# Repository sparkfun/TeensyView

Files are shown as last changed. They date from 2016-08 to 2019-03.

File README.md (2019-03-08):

SparkFun TeensyView
========================================

SparkFun TeensyView

[*SparkFun TeensyView (LCD-14048)*](https://www.sparkfun.com/products/14048)

An OLED display for the Teensy 3

Repository Contents
-------------------

* **/Hardware** - Eagle design files (.brd, .sch)
* **/Libraries** - Libraries for use with the TeensyView
* **/Production** - Production panel files (.brd)

Documentation
--------------
* **[Library](https://github.com/sparkfun/SparkFun_TeensyView_Arduino_Library/)** - C++ library for the TeensyView.
* **[Hookup Guide](https://learn.sparkfun.com/tutorials/teensyview-hookup-guide)** - Basic hookup guide for the TeensyView.
* **[SparkFun Fritzing repo](https://github.com/sparkfun/Fritzing_Parts)** - Fritzing diagrams for SparkFun products.
* **[SparkFun 3D Model repo](https://github.com/sparkfun/3D_Models)** - 3D models of SparkFun products. 
* **[SparkFun Graphical Datasheets](https://github.com/sparkfun/Graphical_Datasheets)** -Graphical Datasheets for various SparkFun products.

Product Versions
---------------------------------

* [LCD-14048](https://www.sparkfun.com/products/14048) - TeensyView product.

Compatible products
---------------------------------

* [DEV-13305](https://www.sparkfun.com/products/13305) - Teensy LC
* [DEV-13736](https://www.sparkfun.com/products/13736) - Teensy 3.2
* [DEV-14055](https://www.sparkfun.com/products/14055) - Teensy 3.5
* [DEV-14057](https://www.sparkfun.com/products/14057) - Teensy 3.6
* [DEV-12767](https://www.sparkfun.com/products/12767) - Teensy Audio Board
* [BOB-13311](https://www.sparkfun.com/products/13311) - Teensy 3.1 XBee Adapter
* [PRT-13925](https://www.sparkfun.com/products/13925) - Teensy Header Kit
* [DEV-13996](https://www.sparkfun.com/products/13996) - Teensy Prop Shield LC
* [DEV-13995](https://www.sparkfun.com/products/13995) - Teensy Prop Shield

Version History
---------------
* [V_1.0.0](https://github.com/sparkfun/TeensyView/tree/V_1.0.0) - Initial release

License Information
-------------------

This product is _**open source**_! 

Please review the LICENSE.md file for license information. 

If you have any questions or concerns on licensing, please contact techsupport@sparkfun.com.

Distributed as-is; no warranty is given.

- Your friends at SparkFun.

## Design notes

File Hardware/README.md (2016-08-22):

SparkFun <PRODUCT NAME> Design Files
=====================================

The .sch and .brd files hare are Eagle CAD schematic and PCB design files from SparkFun Electronics.
A freeware version of Eagle can be found [here](http://www.cadsoftusa.com/download-eagle/freeware/).

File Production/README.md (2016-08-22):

SparkFun <PRODUCT NAME> Production Files
=========================================

These are the production files SparkFun uses for printing PCBs.

License Information
-------------------
This product is open source! 

The hardware is released under [Creative Commons ShareAlike 4.0 International](https://creativecommons.org/licenses/by-sa/4.0/).

Please use, reuse, and modify these files as you see fit. Please maintain attribution to SparkFun Electronics and release anything derivative under the same license.

Distributed as-is; no warranty is given.

- Your friends at SparkFun.

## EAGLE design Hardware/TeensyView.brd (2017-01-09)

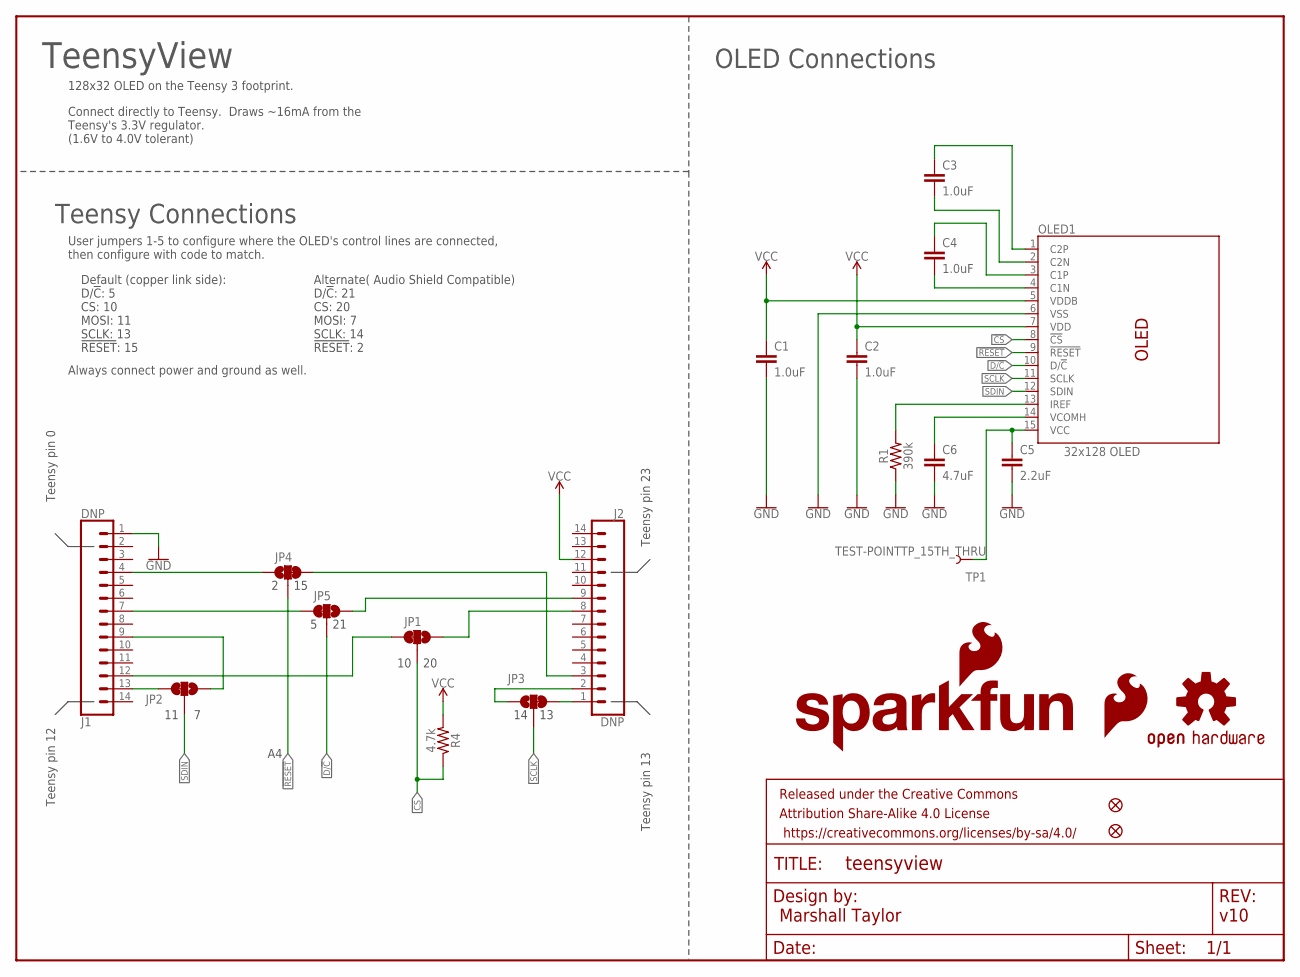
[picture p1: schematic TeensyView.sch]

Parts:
C1, C2, C3, C4: 1.0uF; 0402
C5: 2.2uF; 0805
C6: 4.7uF; 1206
FD1, FD2: FIDUCIALUFIDUCIAL; FIDUCIAL-MICRO
FRAME1: FRAME-LETTER; CREATIVE_COMMONS
J1, J2: DNP; 1X14_NO_SILK
JP1, JP2, JP3, JP4, JP5: JUMPER-SMT_3_1-NC_TRACE_SILK; SMT-JUMPER_3_1-NC_TRACE_SILK
LOGO1: SFE_LOGO_FLAME.1_INCH; SFE_LOGO_FLAME_.1
LOGO2: OSHW-LOGOS; OSHW-LOGO-S
LOGO3: SFE_LOGO_NAME_FLAME.1_INCH; SFE_LOGO_NAME_FLAME_.1
OLED1: 32x128 OLED; OLED-UG-2832TSWGG01-REAR
R1: 390k; 0603
R4: 4.7k; 0603
TP1: TEST-POINTTP_15TH_THRU; TP_15TH

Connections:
!CS: JP1.2, OLED1.8 (!CS!), R4.1
!RESET: JP4.2, OLED1.9 (!RESET!)
D/!C: JP5.2, OLED1.10 (D/!C!)
GND: C1.2, C2.2, C5.2, C6.2, J1.1, OLED1.6 (VSS), R1.1
unnamed: J1.12, JP1.3
unnamed: J2.8, JP1.1
unnamed: C4.2, OLED1.4 (C1N)
unnamed: C4.1, OLED1.3 (C1P)
unnamed: C3.2, OLED1.2 (C2N)
unnamed: C3.1, OLED1.1 (C2P)
unnamed: OLED1.13 (IREF), R1.2
unnamed: C6.1, OLED1.14 (VCOMH)
unnamed: C5.1, OLED1.15 (VCC), TP1.P$1
unnamed: J2.1, JP3.3
unnamed: J2.2, JP3.1
unnamed: J1.13, JP2.3
unnamed: J1.9, JP2.1
unnamed: J2.3, JP4.3
unnamed: J1.4, JP4.1
unnamed: J1.7, JP5.3
unnamed: J2.9, JP5.1
SCLK: JP3.2, OLED1.11 (SCLK)
SDIN: JP2.2, OLED1.12 (SDIN)
VCC: C1.1, C2.1, J2.12, OLED1.5 (VDDB), OLED1.7 (VDD), R4.2

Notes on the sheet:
v10
Marshall Taylor
Teensy pin 0
Teensy pin 12
Teensy pin 13
Teensy pin 23
128x32 OLED on the Teensy 3 footprint.
User jumpers 1-5 to configure where the OLED's control lines are connected, then configure with code to match.
TeensyView
Connect directly to Teensy. Draws ~16mA from the Teensy's 3.3V regulator. (1.6V to 4.0V tolerant)
Teensy Connections
OLED Connections
Default (copper link side): D/!C!: 5 CS: 10 MOSI: 11 SCLK: 13 !RESET!: 15
Alternate( Audio Shield Compatible) D/!C!: 21 CS: 20 MOSI: 7 SCLK: 14 !RESET!: 2
Always connect power and ground as well.

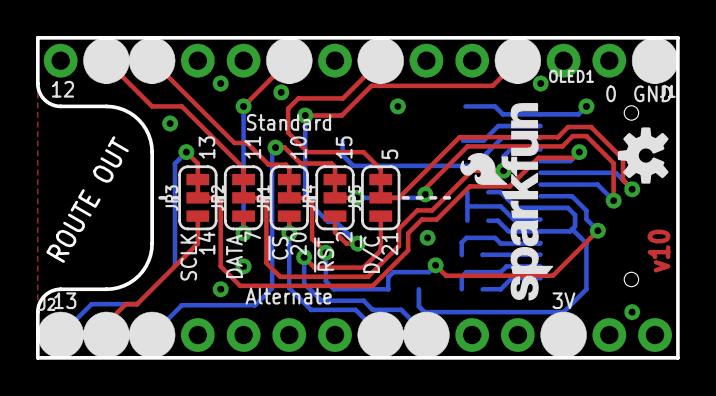
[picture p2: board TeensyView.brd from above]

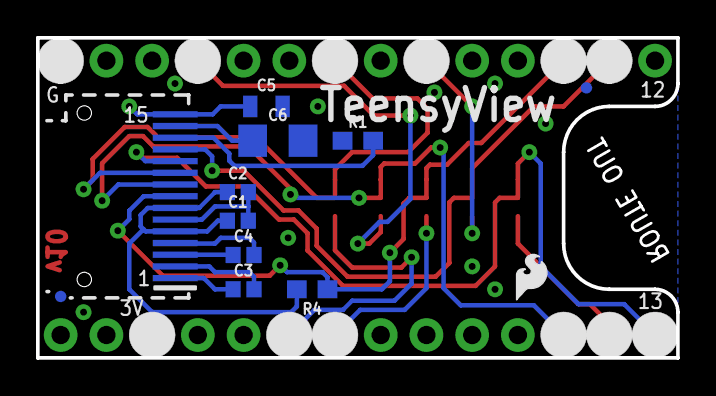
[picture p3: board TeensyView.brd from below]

Board: 2 copper layers, 35.6 x 17.8 mm, 23 parts (12 on the bottom side), 24 nets.

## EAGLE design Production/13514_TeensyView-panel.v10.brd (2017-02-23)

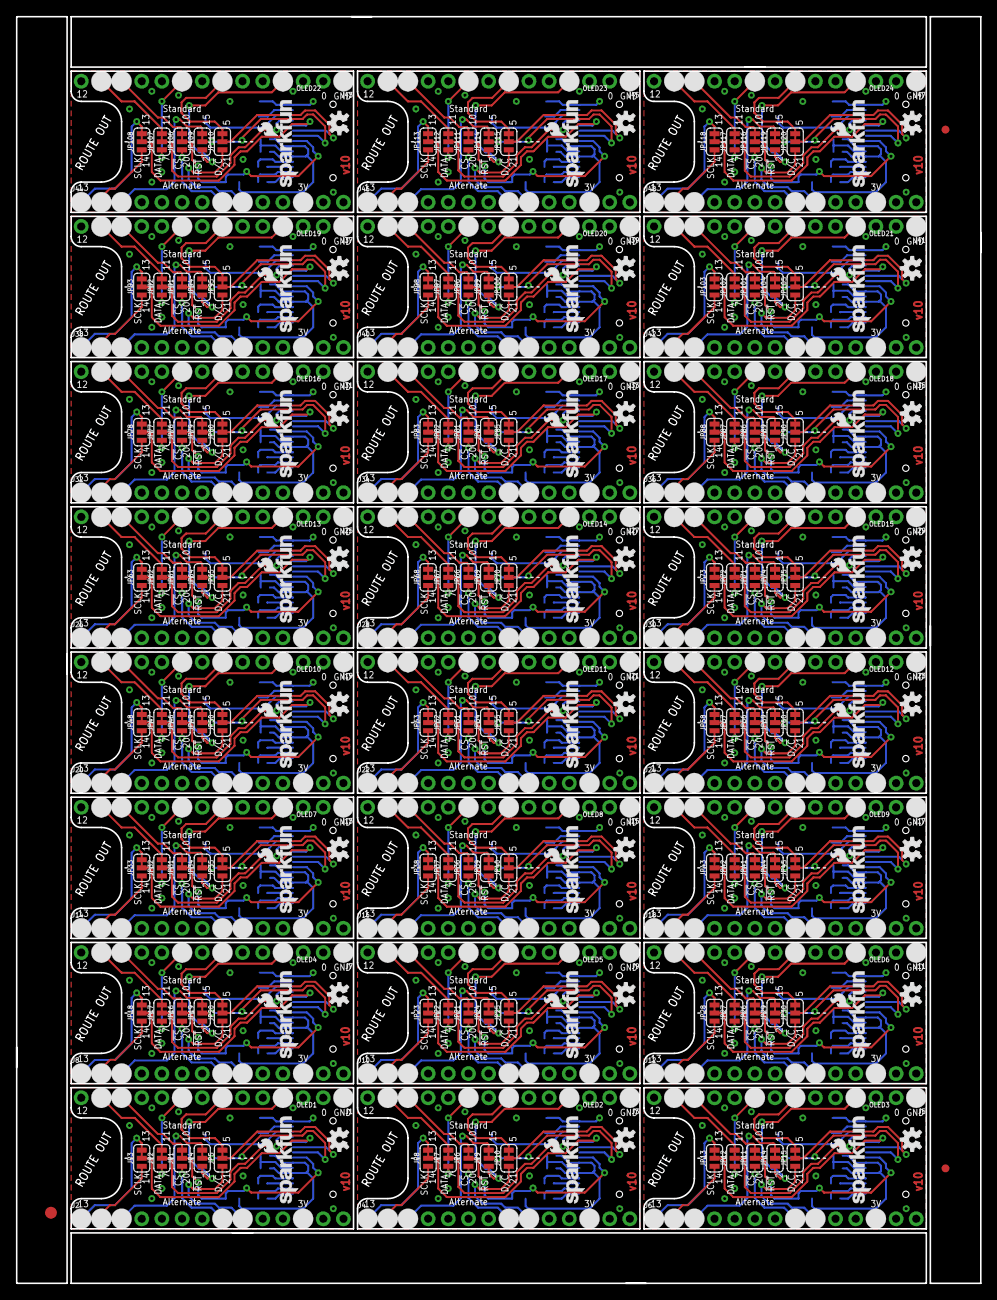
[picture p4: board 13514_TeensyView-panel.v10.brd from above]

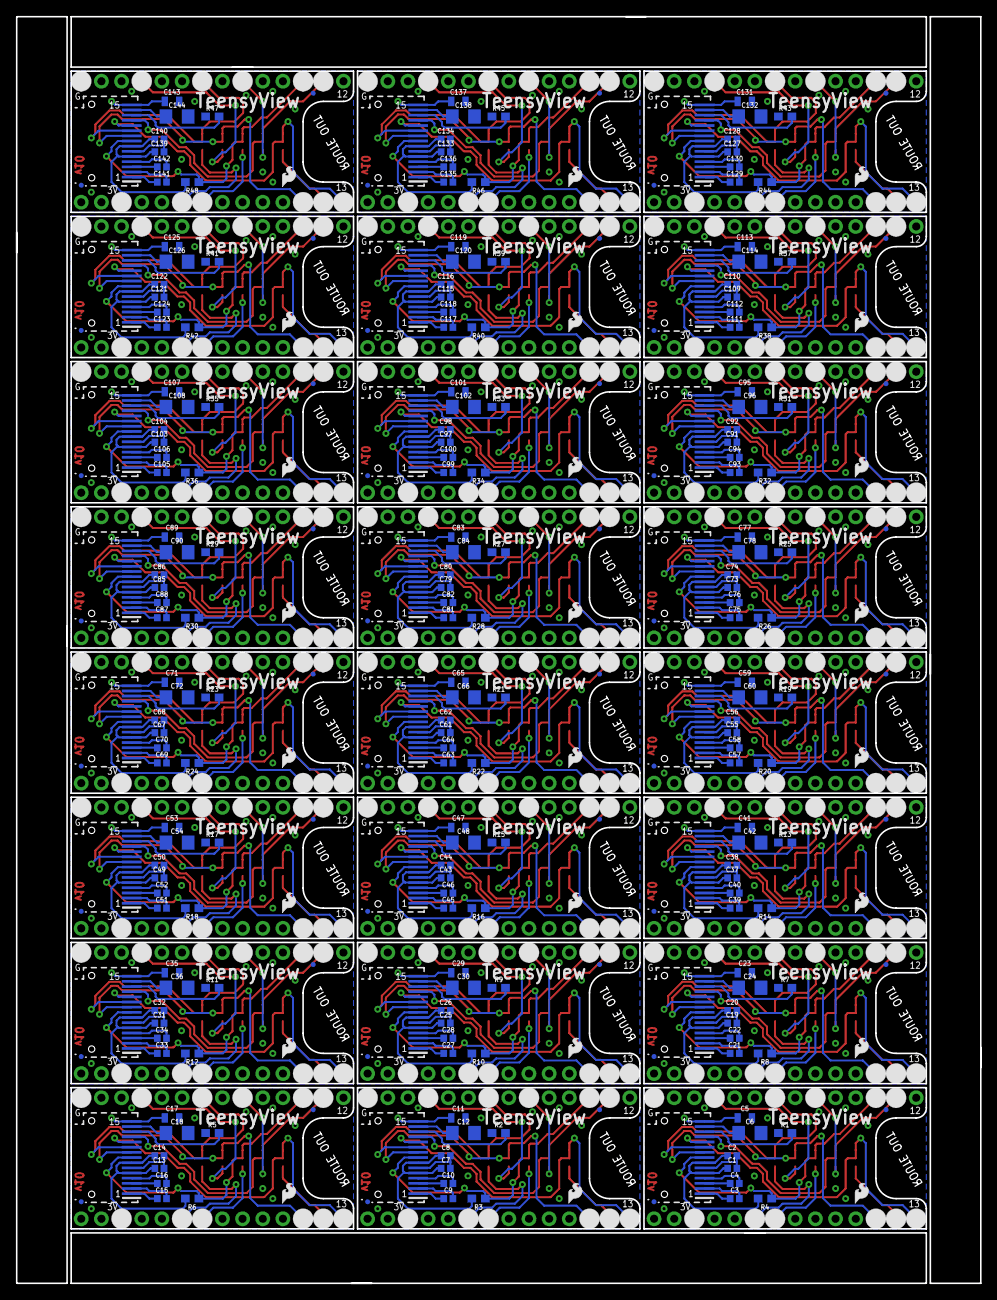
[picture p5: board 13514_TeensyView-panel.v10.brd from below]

Board: 2 copper layers, 121.4 x 159.5 mm, 531 parts (288 on the bottom side), 576 nets.

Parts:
C1, C2, C3, C4, C7, C8, C9, C10, C13, C14, C15, C16, C19, C20, C21, C22, C25, C26, C27, C28, C31, C32, C33, C34, C37, C38, C39, C40, C43, C44, C45, C46, C49, C50, C51, C52, C55, C56, C57, C58, C61, C62, C63, C64, C67, C68, C69, C70, C73, C74, C75, C76, C79, C80, C81, C82, C85, C86, C87, C88, C91, C92, C93, C94, C97, C98, C99, C100, C103, C104, C105, C106, C109, C110, C111, C112, C115, C116, C117, C118, C121, C122, C123, C124, C127, C128, C129, C130, C133, C134, C135, C136, C139, C140, C141, C142: 1.0uF; 0402
C5, C11, C17, C23, C29, C35, C41, C47, C53, C59, C65, C71, C77, C83, C89, C95, C101, C107, C113, C119, C125, C131, C137, C143: 2.2uF; 0805
C6, C12, C18, C24, C30, C36, C42, C48, C54, C60, C66, C72, C78, C84, C90, C96, C102, C108, C114, C120, C126, C132, C138, C144: 4.7uF; 1206
E$1: FIDUCIAL-1.5X3
E$7, E$8: FIDUCIAL-1X2
FD1, FD2, FD3, FD4, FD5, FD6, FD7, FD8, FD9, FD10, FD11, FD12, FD13, FD14, FD15, FD16, FD17, FD18, FD19, FD20, FD21, FD22, FD23, FD24, FD25, FD26, FD27, FD28, FD29, FD30, FD31, FD32, FD33, FD34, FD35, FD36, FD37, FD38, FD39, FD40, FD41, FD42, FD43, FD44, FD45, FD46, FD47, FD48: FIDUCIALUFIDUCIAL; FIDUCIAL-MICRO
J1, J2, J3, J4, J5, J6, J7, J8, J9, J10, J11, J12, J13, J14, J15, J16, J17, J18, J19, J20, J21, J22, J23, J24, J25, J26, J27, J28, J29, J30, J31, J32, J33, J34, J35, J36, J37, J38, J39, J40, J41, J42, J43, J44, J45, J46, J47, J48: DNP; 1X14_NO_SILK
JP1, JP2, JP3, JP4, JP5, JP6, JP7, JP8, JP9, JP10, JP11, JP12, JP13, JP14, JP15, JP16, JP17, JP18, JP19, JP20, JP21, JP22, JP23, JP24, JP25, JP26, JP27, JP28, JP29, JP30, JP31, JP32, JP33, JP34, JP35, JP36, JP37, JP38, JP39, JP40, JP41, JP42, JP43, JP44, JP45, JP46, JP47, JP48, JP49, JP50, JP51, JP52, JP53, JP54, JP55, JP56, JP57, JP58, JP59, JP60, JP61, JP62, JP63, JP64, JP65, JP66, JP67, JP68, JP69, JP70, JP71, JP72, JP73, JP74, JP75, JP76, JP77, JP78, JP79, JP80, JP81, JP82, JP83, JP84, JP85, JP86, JP87, JP88, JP89, JP90, JP91, JP92, JP93, JP94, JP95, JP96, JP97, JP98, JP99, JP100, JP101, JP102, JP103, JP104, JP105, JP106, JP107, JP108, JP109, JP110, JP111, JP112, JP113, JP114, JP115, JP116, JP117, JP118, JP119, JP120: JUMPER-SMT_3_1-NC_TRACE_SILK; SMT-JUMPER_3_1-NC_TRACE_SILK
LOGO1, LOGO4, LOGO7, LOGO10, LOGO13, LOGO16, LOGO19, LOGO22, LOGO25, LOGO28, LOGO31, LOGO34, LOGO37, LOGO40, LOGO43, LOGO46, LOGO49, LOGO52, LOGO55, LOGO58, LOGO61, LOGO64, LOGO67, LOGO70: SFE_LOGO_FLAME.1_INCH; SFE_LOGO_FLAME_.1
LOGO2, LOGO5, LOGO8, LOGO11, LOGO14, LOGO17, LOGO20, LOGO23, LOGO26, LOGO29, LOGO32, LOGO35, LOGO38, LOGO41, LOGO44, LOGO47, LOGO50, LOGO53, LOGO56, LOGO59, LOGO62, LOGO65, LOGO68, LOGO71: OSHW-LOGOS; OSHW-LOGO-S
LOGO3, LOGO6, LOGO9, LOGO12, LOGO15, LOGO18, LOGO21, LOGO24, LOGO27, LOGO30, LOGO33, LOGO36, LOGO39, LOGO42, LOGO45, LOGO48, LOGO51, LOGO54, LOGO57, LOGO60, LOGO63, LOGO66, LOGO69, LOGO72: SFE_LOGO_NAME_FLAME.1_INCH; SFE_LOGO_NAME_FLAME_.1
OLED1, OLED2, OLED3, OLED4, OLED5, OLED6, OLED7, OLED8, OLED9, OLED10, OLED11, OLED12, OLED13, OLED14, OLED15, OLED16, OLED17, OLED18, OLED19, OLED20, OLED21, OLED22, OLED23, OLED24: 32x128 OLED; OLED-UG-2832TSWGG01-REAR
R1, R2, R5, R7, R9, R11, R13, R15, R17, R19, R21, R23, R25, R27, R29, R31, R33, R35, R37, R39, R41, R43, R45, R47: 390k; 0603
R3, R4, R6, R8, R10, R12, R14, R16, R18, R20, R22, R24, R26, R28, R30, R32, R34, R36, R38, R40, R42, R44, R46, R48: 4.7k; 0603
TP1, TP2, TP3, TP4, TP5, TP6, TP7, TP8, TP9, TP10, TP11, TP12, TP13, TP14, TP15, TP16, TP17, TP18, TP19, TP20, TP21, TP22, TP23, TP24: TEST-POINTTP_15TH_THRU; TP_15TH

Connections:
!CS: JP1.2, OLED1.8, R4.1
!CS1: JP6.2, OLED2.8, R3.1
!CS2: JP11.2, OLED3.8, R6.1
!CS3: JP16.2, OLED4.8, R8.1
!CS4: JP21.2, OLED5.8, R10.1
!CS5: JP26.2, OLED6.8, R12.1
!CS6: JP31.2, OLED7.8, R14.1
!CS7: JP36.2, OLED8.8, R16.1
!CS8: JP41.2, OLED9.8, R18.1
!CS9: JP46.2, OLED10.8, R20.1
!CS10: JP51.2, OLED11.8, R22.1
!CS11: JP56.2, OLED12.8, R24.1
!CS12: JP61.2, OLED13.8, R26.1
!CS13: JP66.2, OLED14.8, R28.1
!CS14: JP71.2, OLED15.8, R30.1
!CS15: JP76.2, OLED16.8, R32.1
!CS16: JP81.2, OLED17.8, R34.1
!CS17: JP86.2, OLED18.8, R36.1
!CS18: JP91.2, OLED19.8, R38.1
!CS19: JP96.2, OLED20.8, R40.1
!CS20: JP101.2, OLED21.8, R42.1
!CS21: JP106.2, OLED22.8, R44.1
!CS22: JP111.2, OLED23.8, R46.1
!CS23: JP116.2, OLED24.8, R48.1
!RESET: JP4.2, OLED1.9
!RESET1: JP9.2, OLED2.9
!RESET2: JP14.2, OLED3.9
!RESET3: JP19.2, OLED4.9
!RESET4: JP24.2, OLED5.9
!RESET5: JP29.2, OLED6.9
!RESET6: JP34.2, OLED7.9
!RESET7: JP39.2, OLED8.9
!RESET8: JP44.2, OLED9.9
!RESET9: JP49.2, OLED10.9
!RESET10: JP54.2, OLED11.9
!RESET11: JP59.2, OLED12.9
!RESET12: JP64.2, OLED13.9
!RESET13: JP69.2, OLED14.9
!RESET14: JP74.2, OLED15.9
!RESET15: JP79.2, OLED16.9
!RESET16: JP84.2, OLED17.9
!RESET17: JP89.2, OLED18.9
!RESET18: JP94.2, OLED19.9
!RESET19: JP99.2, OLED20.9
!RESET20: JP104.2, OLED21.9
!RESET21: JP109.2, OLED22.9
!RESET22: JP114.2, OLED23.9
!RESET23: JP119.2, OLED24.9
D/!C: JP5.2, OLED1.10
D/!C1: JP10.2, OLED2.10
D/!C2: JP15.2, OLED3.10
D/!C3: JP20.2, OLED4.10
D/!C4: JP25.2, OLED5.10
D/!C5: JP30.2, OLED6.10
D/!C6: JP35.2, OLED7.10
D/!C7: JP40.2, OLED8.10
D/!C8: JP45.2, OLED9.10
D/!C9: JP50.2, OLED10.10
D/!C10: JP55.2, OLED11.10
D/!C11: JP60.2, OLED12.10
D/!C12: JP65.2, OLED13.10
D/!C13: JP70.2, OLED14.10
D/!C14: JP75.2, OLED15.10
D/!C15: JP80.2, OLED16.10
D/!C16: JP85.2, OLED17.10
D/!C17: JP90.2, OLED18.10
D/!C18: JP95.2, OLED19.10
D/!C19: JP100.2, OLED20.10
D/!C20: JP105.2, OLED21.10
D/!C21: JP110.2, OLED22.10
D/!C22: JP115.2, OLED23.10
D/!C23: JP120.2, OLED24.10
GND: C1.2, C2.2, C5.2, C6.2, J1.1, OLED1.6, R1.1
GND1: C7.2, C8.2, C11.2, C12.2, J3.1, OLED2.6, R2.1
GND2: C13.2, C14.2, C17.2, C18.2, J5.1, OLED3.6, R5.1
GND3: C19.2, C20.2, C23.2, C24.2, J7.1, OLED4.6, R7.1
GND4: C25.2, C26.2, C29.2, C30.2, J9.1, OLED5.6, R9.1
GND5: C31.2, C32.2, C35.2, C36.2, J11.1, OLED6.6, R11.1
GND6: C37.2, C38.2, C41.2, C42.2, J13.1, OLED7.6, R13.1
GND7: C43.2, C44.2, C47.2, C48.2, J15.1, OLED8.6, R15.1
GND8: C49.2, C50.2, C53.2, C54.2, J17.1, OLED9.6, R17.1
GND9: C55.2, C56.2, C59.2, C60.2, J19.1, OLED10.6, R19.1
GND10: C61.2, C62.2, C65.2, C66.2, J21.1, OLED11.6, R21.1
GND11: C67.2, C68.2, C71.2, C72.2, J23.1, OLED12.6, R23.1
GND12: C73.2, C74.2, C77.2, C78.2, J25.1, OLED13.6, R25.1
GND13: C79.2, C80.2, C83.2, C84.2, J27.1, OLED14.6, R27.1
GND14: C85.2, C86.2, C89.2, C90.2, J29.1, OLED15.6, R29.1
GND15: C91.2, C92.2, C95.2, C96.2, J31.1, OLED16.6, R31.1
GND16: C97.2, C98.2, C101.2, C102.2, J33.1, OLED17.6, R33.1
GND17: C103.2, C104.2, C107.2, C108.2, J35.1, OLED18.6, R35.1
GND18: C109.2, C110.2, C113.2, C114.2, J37.1, OLED19.6, R37.1
GND19: C115.2, C116.2, C119.2, C120.2, J39.1, OLED20.6, R39.1
GND20: C121.2, C122.2, C125.2, C126.2, J41.1, OLED21.6, R41.1
GND21: C127.2, C128.2, C131.2, C132.2, J43.1, OLED22.6, R43.1
GND22: C133.2, C134.2, C137.2, C138.2, J45.1, OLED23.6, R45.1
GND23: C139.2, C140.2, C143.2, C144.2, J47.1, OLED24.6, R47.1
unnamed: J1.12, JP1.3
unnamed: J2.8, JP1.1
unnamed: C4.2, OLED1.4
unnamed: C4.1, OLED1.3
unnamed: C3.2, OLED1.2
unnamed: C3.1, OLED1.1
unnamed: OLED1.13, R1.2
unnamed: C6.1, OLED1.14
unnamed: C5.1, OLED1.15, TP1.P$1
unnamed: J2.1, JP3.3
unnamed: J2.2, JP3.1
unnamed: J1.13, JP2.3
unnamed: J1.9, JP2.1
unnamed: J2.3, JP4.3
unnamed: J1.4, JP4.1
unnamed: J1.7, JP5.3
unnamed: J2.9, JP5.1
unnamed: C10.2, OLED2.4
unnamed: C10.1, OLED2.3
unnamed: C9.2, OLED2.2
unnamed: C9.1, OLED2.1
unnamed: OLED2.13, R2.2
unnamed: C12.1, OLED2.14
unnamed: C11.1, OLED2.15, TP2.P$1
unnamed: J3.12, JP6.3
unnamed: J4.2, JP8.1
unnamed: J4.1, JP8.3
unnamed: J3.13, JP7.3
unnamed: J3.9, JP7.1
unnamed: J4.8, JP6.1
unnamed: J4.3, JP9.3
unnamed: J3.4, JP9.1
unnamed: J3.7, JP10.3
unnamed: J4.9, JP10.1
unnamed: C16.2, OLED3.4
unnamed: C16.1, OLED3.3
unnamed: C15.2, OLED3.2
unnamed: C15.1, OLED3.1
unnamed: OLED3.13, R5.2
unnamed: C18.1, OLED3.14
unnamed: C17.1, OLED3.15, TP3.P$1
unnamed: J5.12, JP11.3
unnamed: J6.2, JP13.1
unnamed: J6.1, JP13.3
unnamed: J5.13, JP12.3
unnamed: J5.9, JP12.1
unnamed: J6.8, JP11.1
unnamed: J6.3, JP14.3
unnamed: J5.4, JP14.1
unnamed: J5.7, JP15.3
unnamed: J6.9, JP15.1
unnamed: C22.2, OLED4.4
unnamed: C22.1, OLED4.3
unnamed: C21.2, OLED4.2
unnamed: C21.1, OLED4.1
unnamed: OLED4.13, R7.2
unnamed: C24.1, OLED4.14
unnamed: C23.1, OLED4.15, TP4.P$1
unnamed: J7.12, JP16.3
unnamed: J8.2, JP18.1
unnamed: J8.1, JP18.3
unnamed: J7.13, JP17.3
unnamed: J7.9, JP17.1
unnamed: J8.8, JP16.1
unnamed: J8.3, JP19.3
unnamed: J7.4, JP19.1
unnamed: J7.7, JP20.3
unnamed: J8.9, JP20.1
unnamed: C28.2, OLED5.4
unnamed: C28.1, OLED5.3
unnamed: C27.2, OLED5.2
unnamed: C27.1, OLED5.1
unnamed: OLED5.13, R9.2
unnamed: C30.1, OLED5.14
unnamed: C29.1, OLED5.15, TP5.P$1
unnamed: J9.12, JP21.3
unnamed: J10.2, JP23.1
unnamed: J10.1, JP23.3
unnamed: J9.13, JP22.3
unnamed: J9.9, JP22.1
unnamed: J10.8, JP21.1
unnamed: J10.3, JP24.3
unnamed: J9.4, JP24.1
unnamed: J9.7, JP25.3
unnamed: J10.9, JP25.1
unnamed: C34.2, OLED6.4
unnamed: C34.1, OLED6.3
unnamed: C33.2, OLED6.2
unnamed: C33.1, OLED6.1
unnamed: OLED6.13, R11.2
unnamed: C36.1, OLED6.14
unnamed: C35.1, OLED6.15, TP6.P$1
unnamed: J11.12, JP26.3
unnamed: J12.2, JP28.1
unnamed: J12.1, JP28.3
unnamed: J11.13, JP27.3
unnamed: J11.9, JP27.1
unnamed: J12.8, JP26.1
unnamed: J12.3, JP29.3
unnamed: J11.4, JP29.1
unnamed: J11.7, JP30.3
unnamed: J12.9, JP30.1
unnamed: C40.2, OLED7.4
unnamed: C40.1, OLED7.3
unnamed: C39.2, OLED7.2
unnamed: C39.1, OLED7.1
unnamed: OLED7.13, R13.2
unnamed: C42.1, OLED7.14
unnamed: C41.1, OLED7.15, TP7.P$1
unnamed: J13.12, JP31.3
unnamed: J14.2, JP33.1
unnamed: J14.1, JP33.3
unnamed: J13.13, JP32.3
unnamed: J13.9, JP32.1
unnamed: J14.8, JP31.1
unnamed: J14.3, JP34.3
unnamed: J13.4, JP34.1
unnamed: J13.7, JP35.3
unnamed: J14.9, JP35.1
unnamed: C46.2, OLED8.4
unnamed: C46.1, OLED8.3
unnamed: C45.2, OLED8.2
unnamed: C45.1, OLED8.1
unnamed: OLED8.13, R15.2
unnamed: C48.1, OLED8.14
unnamed: C47.1, OLED8.15, TP8.P$1
unnamed: J15.12, JP36.3
unnamed: J16.2, JP38.1
unnamed: J16.1, JP38.3
unnamed: J15.13, JP37.3
unnamed: J15.9, JP37.1
unnamed: J16.8, JP36.1
unnamed: J16.3, JP39.3
unnamed: J15.4, JP39.1
unnamed: J15.7, JP40.3
unnamed: J16.9, JP40.1
unnamed: C52.2, OLED9.4
unnamed: C52.1, OLED9.3
unnamed: C51.2, OLED9.2
unnamed: C51.1, OLED9.1
unnamed: OLED9.13, R17.2
unnamed: C54.1, OLED9.14
unnamed: C53.1, OLED9.15, TP9.P$1
unnamed: J17.12, JP41.3
unnamed: J18.2, JP43.1
unnamed: J18.1, JP43.3
unnamed: J17.13, JP42.3
unnamed: J17.9, JP42.1
unnamed: J18.8, JP41.1
unnamed: J18.3, JP44.3
unnamed: J17.4, JP44.1
unnamed: J17.7, JP45.3
unnamed: J18.9, JP45.1
unnamed: C58.2, OLED10.4
unnamed: C58.1, OLED10.3
unnamed: C57.2, OLED10.2
unnamed: C57.1, OLED10.1
unnamed: OLED10.13, R19.2
unnamed: C60.1, OLED10.14
unnamed: C59.1, OLED10.15, TP10.P$1
unnamed: J19.12, JP46.3
unnamed: J20.2, JP48.1
unnamed: J20.1, JP48.3
unnamed: J19.13, JP47.3
unnamed: J19.9, JP47.1
unnamed: J20.8, JP46.1
unnamed: J20.3, JP49.3
unnamed: J19.4, JP49.1
unnamed: J19.7, JP50.3
unnamed: J20.9, JP50.1
unnamed: C64.2, OLED11.4
unnamed: C64.1, OLED11.3
unnamed: C63.2, OLED11.2
unnamed: C63.1, OLED11.1
unnamed: OLED11.13, R21.2
unnamed: C66.1, OLED11.14
unnamed: C65.1, OLED11.15, TP11.P$1
unnamed: J21.12, JP51.3
unnamed: J22.2, JP53.1
unnamed: J22.1, JP53.3
unnamed: J21.13, JP52.3
unnamed: J21.9, JP52.1
unnamed: J22.8, JP51.1
unnamed: J22.3, JP54.3
unnamed: J21.4, JP54.1
unnamed: J21.7, JP55.3
unnamed: J22.9, JP55.1
unnamed: C70.2, OLED12.4
unnamed: C70.1, OLED12.3
unnamed: C69.2, OLED12.2
unnamed: C69.1, OLED12.1
unnamed: OLED12.13, R23.2
unnamed: C72.1, OLED12.14
unnamed: C71.1, OLED12.15, TP12.P$1
unnamed: J23.12, JP56.3
unnamed: J24.2, JP58.1
unnamed: J24.1, JP58.3
unnamed: J23.13, JP57.3
unnamed: J23.9, JP57.1
unnamed: J24.8, JP56.1
unnamed: J24.3, JP59.3
unnamed: J23.4, JP59.1
unnamed: J23.7, JP60.3
unnamed: J24.9, JP60.1
unnamed: C76.2, OLED13.4
unnamed: C76.1, OLED13.3
unnamed: C75.2, OLED13.2
unnamed: C75.1, OLED13.1
unnamed: OLED13.13, R25.2
unnamed: C78.1, OLED13.14
unnamed: C77.1, OLED13.15, TP13.P$1
unnamed: J25.12, JP61.3
unnamed: J26.2, JP63.1
unnamed: J26.1, JP63.3
unnamed: J25.13, JP62.3
unnamed: J25.9, JP62.1
unnamed: J26.8, JP61.1
unnamed: J26.3, JP64.3
unnamed: J25.4, JP64.1
unnamed: J25.7, JP65.3
unnamed: J26.9, JP65.1
unnamed: C82.2, OLED14.4
unnamed: C82.1, OLED14.3
unnamed: C81.2, OLED14.2
unnamed: C81.1, OLED14.1
unnamed: OLED14.13, R27.2
unnamed: C84.1, OLED14.14
unnamed: C83.1, OLED14.15, TP14.P$1
unnamed: J27.12, JP66.3
unnamed: J28.2, JP68.1
unnamed: J28.1, JP68.3
unnamed: J27.13, JP67.3
unnamed: J27.9, JP67.1
unnamed: J28.8, JP66.1
unnamed: J28.3, JP69.3
unnamed: J27.4, JP69.1
unnamed: J27.7, JP70.3
unnamed: J28.9, JP70.1
unnamed: C88.2, OLED15.4
unnamed: C88.1, OLED15.3
unnamed: C87.2, OLED15.2
unnamed: C87.1, OLED15.1
unnamed: OLED15.13, R29.2
unnamed: C90.1, OLED15.14
unnamed: C89.1, OLED15.15, TP15.P$1
unnamed: J29.12, JP71.3
unnamed: J30.2, JP73.1
unnamed: J30.1, JP73.3
unnamed: J29.13, JP72.3
unnamed: J29.9, JP72.1
unnamed: J30.8, JP71.1
unnamed: J30.3, JP74.3
unnamed: J29.4, JP74.1
unnamed: J29.7, JP75.3
unnamed: J30.9, JP75.1
unnamed: C94.2, OLED16.4
unnamed: C94.1, OLED16.3
unnamed: C93.2, OLED16.2
unnamed: C93.1, OLED16.1
unnamed: OLED16.13, R31.2
unnamed: C96.1, OLED16.14
unnamed: C95.1, OLED16.15, TP16.P$1
unnamed: J31.12, JP76.3
unnamed: J32.2, JP78.1
unnamed: J32.1, JP78.3
unnamed: J31.13, JP77.3
unnamed: J31.9, JP77.1
unnamed: J32.8, JP76.1
unnamed: J32.3, JP79.3
unnamed: J31.4, JP79.1
unnamed: J31.7, JP80.3
unnamed: J32.9, JP80.1
unnamed: C100.2, OLED17.4
unnamed: C100.1, OLED17.3
unnamed: C99.2, OLED17.2
unnamed: C99.1, OLED17.1
unnamed: OLED17.13, R33.2
unnamed: C102.1, OLED17.14
unnamed: C101.1, OLED17.15, TP17.P$1
unnamed: J33.12, JP81.3
unnamed: J34.2, JP83.1
unnamed: J34.1, JP83.3
unnamed: J33.13, JP82.3
unnamed: J33.9, JP82.1
unnamed: J34.8, JP81.1
unnamed: J34.3, JP84.3
unnamed: J33.4, JP84.1
unnamed: J33.7, JP85.3
unnamed: J34.9, JP85.1
unnamed: C106.2, OLED18.4
unnamed: C106.1, OLED18.3
unnamed: C105.2, OLED18.2
unnamed: C105.1, OLED18.1
unnamed: OLED18.13, R35.2
unnamed: C108.1, OLED18.14
unnamed: C107.1, OLED18.15, TP18.P$1
unnamed: J35.12, JP86.3
unnamed: J36.2, JP88.1
unnamed: J36.1, JP88.3
unnamed: J35.13, JP87.3
unnamed: J35.9, JP87.1
unnamed: J36.8, JP86.1
unnamed: J36.3, JP89.3
unnamed: J35.4, JP89.1
unnamed: J35.7, JP90.3
unnamed: J36.9, JP90.1
unnamed: C112.2, OLED19.4
unnamed: C112.1, OLED19.3
unnamed: C111.2, OLED19.2
unnamed: C111.1, OLED19.1
unnamed: OLED19.13, R37.2
unnamed: C114.1, OLED19.14
unnamed: C113.1, OLED19.15, TP19.P$1
unnamed: J37.12, JP91.3
unnamed: J38.2, JP93.1
unnamed: J38.1, JP93.3
unnamed: J37.13, JP92.3
unnamed: J37.9, JP92.1
unnamed: J38.8, JP91.1
unnamed: J38.3, JP94.3
unnamed: J37.4, JP94.1
unnamed: J37.7, JP95.3
unnamed: J38.9, JP95.1
unnamed: C118.2, OLED20.4
unnamed: C118.1, OLED20.3
unnamed: C117.2, OLED20.2
unnamed: C117.1, OLED20.1
unnamed: OLED20.13, R39.2
unnamed: C120.1, OLED20.14
unnamed: C119.1, OLED20.15, TP20.P$1
unnamed: J39.12, JP96.3
unnamed: J40.2, JP98.1
unnamed: J40.1, JP98.3
unnamed: J39.13, JP97.3
unnamed: J39.9, JP97.1
unnamed: J40.8, JP96.1
unnamed: J40.3, JP99.3
unnamed: J39.4, JP99.1
unnamed: J39.7, JP100.3
unnamed: J40.9, JP100.1
unnamed: C124.2, OLED21.4
unnamed: C124.1, OLED21.3
unnamed: C123.2, OLED21.2
unnamed: C123.1, OLED21.1
unnamed: OLED21.13, R41.2
unnamed: C126.1, OLED21.14
unnamed: C125.1, OLED21.15, TP21.P$1
unnamed: J41.12, JP101.3
unnamed: J42.2, JP103.1
unnamed: J42.1, JP103.3
unnamed: J41.13, JP102.3
unnamed: J41.9, JP102.1
unnamed: J42.8, JP101.1
unnamed: J42.3, JP104.3
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

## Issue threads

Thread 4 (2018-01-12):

Enhance to allow use of any SPI controller on Teensy

jrw429, 2018-01-12:
This library is hardcoded to use the first SPI interface on the Teensy. The Teensy can have up to three SPI interfaces. The SPI library for the Teensy will instantiate three instances of the SPIClass if the processor supports it. These objects are called SPI, SPI1 and SPI2. I would like to request an enhancement so that it is possible to specify which SPI interface (which SPIClass object) to use. Optionally passing in the SPIClass object would be one way to do this.

oclyke, 2019-03-08:
Great idea! Check out pull request #6 and let me know if it does what you want. If you can, please test it and let me know if there are any bugs. If there's still a problem then go ahead and re-open this issue.

Closed 2019-03-08.

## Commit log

2016-08-25 Created basic PCB
    [TeensyView.brd, TeensyView.sch]
2016-08-25 Added test boards to design
    [TeensyViewSideTest.brd, TeensyViewSideTest.sch, TeensyViewTopTest.brd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]
2016-09-12 Proto 1 design complete
    [TeensyView.brd, TeensyView.sch, TeensyViewSideTest.brd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]
2016-09-14 Post review fixes
    [TeensyView.brd, TeensyView.sch]
2016-09-15 Resized dimension, moved 1 via and added a couple more
    [TeensyView.brd]
2016-12-05 Going for proto 2
    [TeensyView.brd, TeensyView.sch]
2016-12-06 Moved silk.
    [TeensyView.brd, TeensyView.sch]
2016-12-06 Applied Proto 2 review action items
    [TeensyView.brd, TeensyView.sch]
2016-12-06 Added TP to OLED's VCC
    [TeensyView.brd, TeensyView.sch]
2016-12-08 worked through checklist and updated some parts, moved TP
    [TeensyView.brd, TeensyView.sch]
2017-01-06 Adjusted proto 2 in prep for reds review
    [TeensyView.brd, TeensyView.sch]
2017-01-09 Made silk and version number changes for reds
    [TeensyView.brd, TeensyView.sch]
2017-03-15 Squashed 'Libraries/Arduino/' content from commit 0b28e56
    git-subtree-dir: Libraries/Arduino
    git-subtree-split: 0b28e5669c08754daa54997ed27a598d5a9bf809
    [LEDTestData.ods]
2019-03-08 Add multiple spi support
2019-03-08 Create a demo for custom SPI port usage
    Currently not supporting alternate pin assignment on the SPI ports, but it should be fairly easy to use.
    Also not tested, but it compiles.

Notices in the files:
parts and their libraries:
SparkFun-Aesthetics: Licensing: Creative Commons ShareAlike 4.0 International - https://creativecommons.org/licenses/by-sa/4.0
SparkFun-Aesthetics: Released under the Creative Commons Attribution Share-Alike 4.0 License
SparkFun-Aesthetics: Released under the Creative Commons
